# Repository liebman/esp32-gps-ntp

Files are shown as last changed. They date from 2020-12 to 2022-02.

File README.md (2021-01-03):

# This is an ESP32 NTP Server with DS3231 synched to GPS PPS signal

**NOTE: This is functional but *very much* a work in progress at the moment.**

This is an [esp-idf](https://docs.espressif.com/projects/esp-idf/en/latest/esp32/index.html) app using [platformio](https://platformio.org/).

## Some details

Synching the DS3231 to the GPS is done with a small high level (level 5) interrupt handler in assembly.  This generates a timestamp and offset in microseconds tracking the active edges of the GPS PPS and RTC SQW signals.  This data is then fed in to a PID algorithm that will generate an offset value used to speed up and slow down the DS3231 RTC.  This keeps the DS3231 synced with the GPS to within a couple of microseconds.  As a side benifit it also tunes the DS3231's ocilator to reduce drift when GPS is unavailable.

- [main](main) Contains the code
- [kicad/esp-gps-ntp](kicad/esp-gps-ntp) contains the schematic and board designs in KiCad.
- [kicad/display-adapter](kicad/display-adapter) contains the schematic and board design for a small adapter to config a single inline header connector to an IDC connector (for ribbon cable connection of display)

The display I'm using is [here](https://www.amazon.com/gp/product/B073R7BH1B)

## Schematic

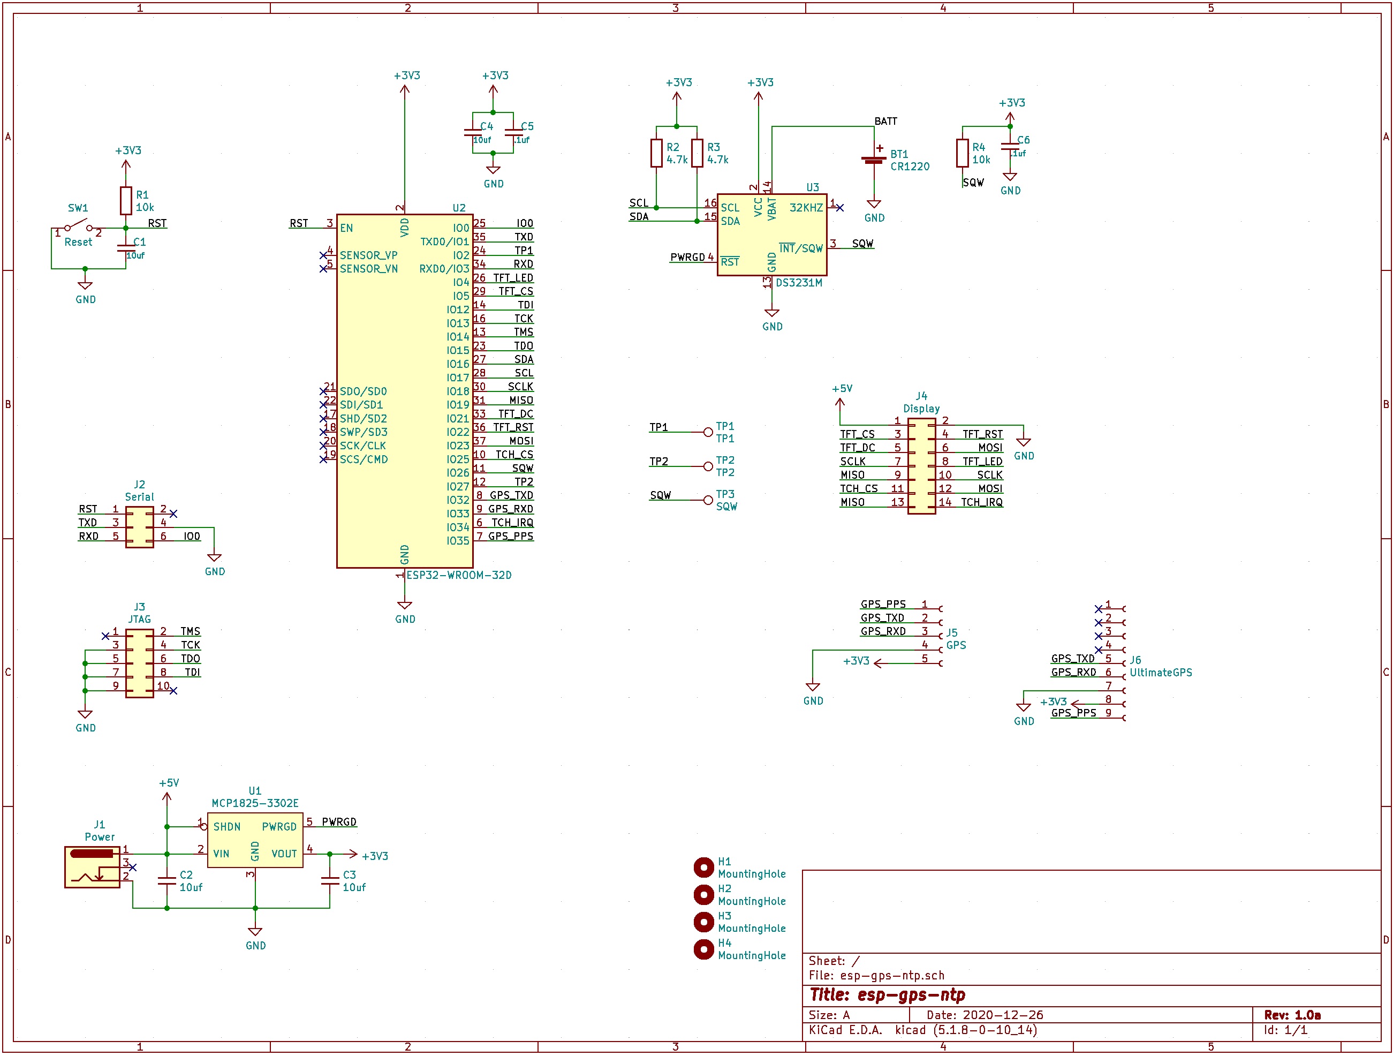
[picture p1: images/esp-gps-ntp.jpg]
Schematic


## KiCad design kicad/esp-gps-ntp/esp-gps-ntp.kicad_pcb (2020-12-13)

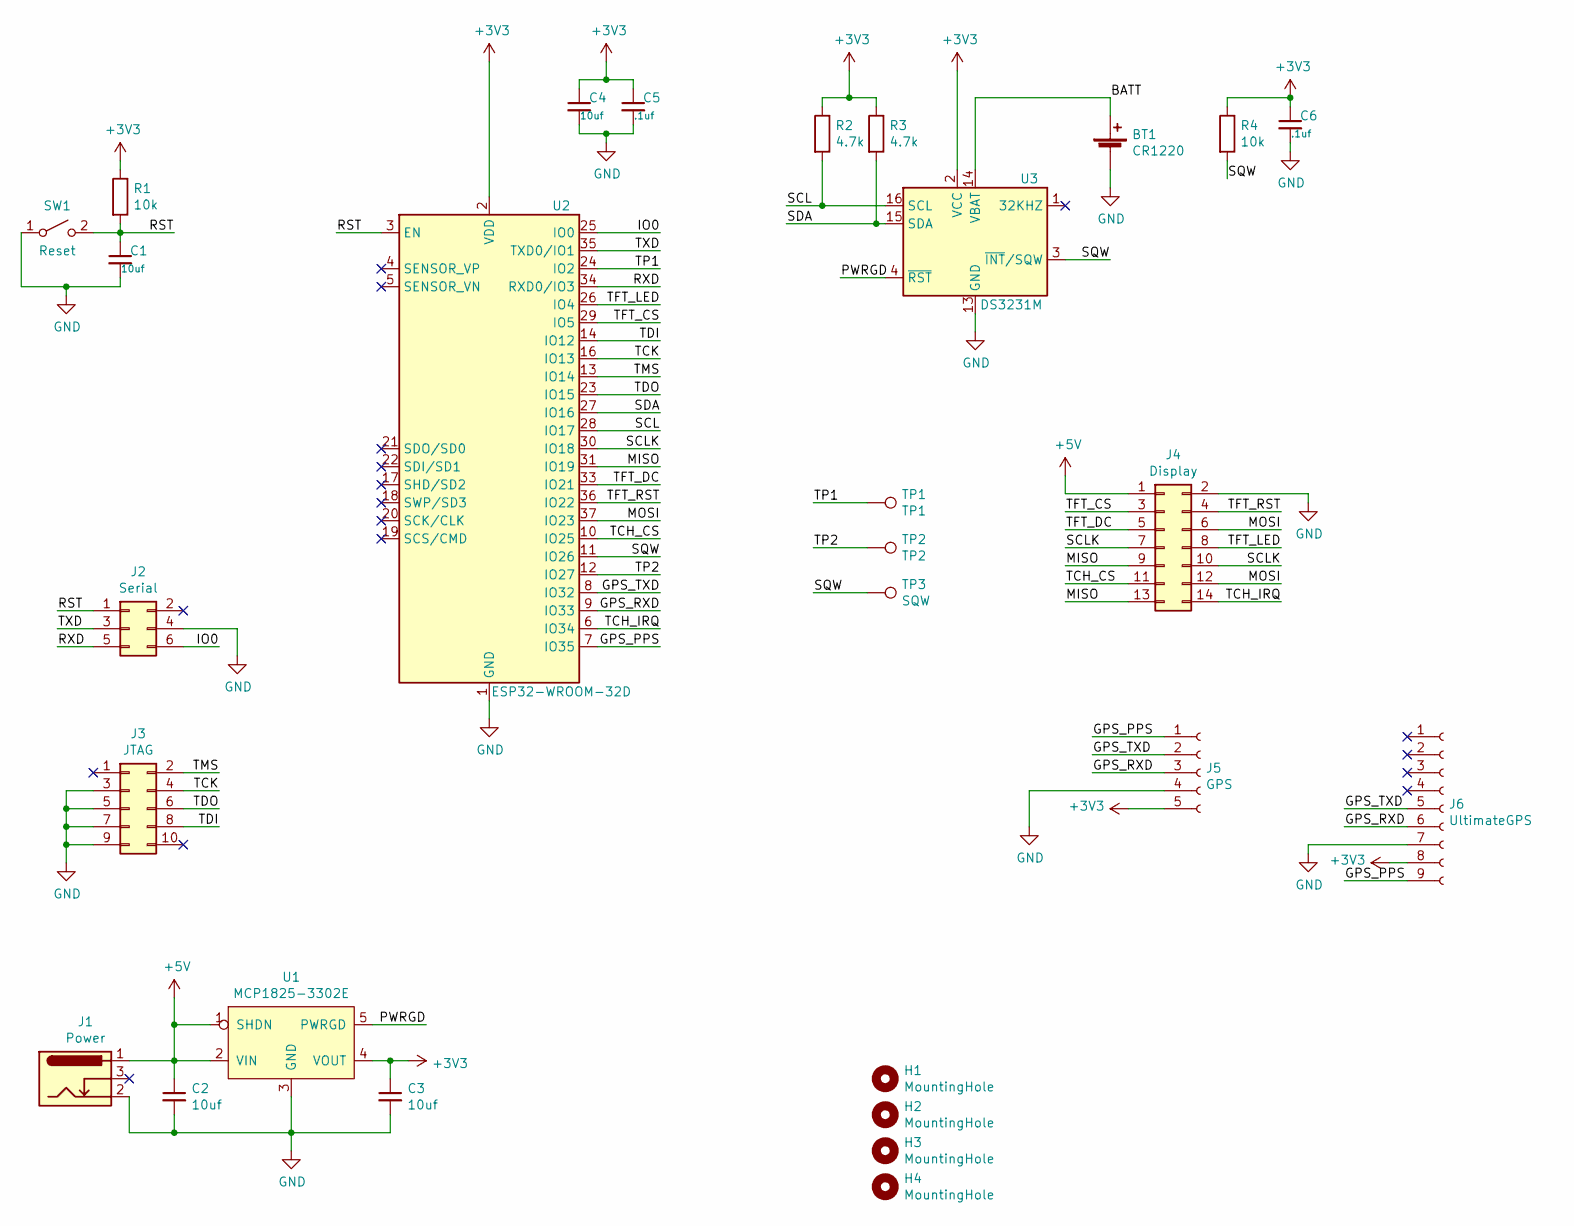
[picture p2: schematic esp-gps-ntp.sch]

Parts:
BT1: CR1220; HARWIN-CR1220
C1, C2, C3, C4: 10uf; C_Disc_D5.0mm_W2.5mm_P5.00mm
C5, C6: .1uf; C_Disc_D5.0mm_W2.5mm_P2.50mm
H1, H2, H3, H4: MountingHole; MountingHole_3.2mm_M3
J1: Power; BarrelJack_Horizontal
J2: Serial; IDC-Header_2x03_P2.54mm_Vertical
J3: JTAG; IDC-Header_2x05_P2.54mm_Vertical
J4: Display; IDC-Header_2x07_P2.54mm_Vertical
J5: GPS; PinSocket_1x05_P2.54mm_Vertical
J6: UltimateGPS; PinSocket_1x09_P2.54mm_Vertical
R1, R4: 10k; R_Axial_DIN0207_L6.3mm_D2.5mm_P7.62mm_Horizontal
R2, R3: 4.7k; R_Axial_DIN0207_L6.3mm_D2.5mm_P7.62mm_Horizontal
SW1: Reset; SW_PUSH_6mm
TP1: TP1; TestPoint_THTPad_2.5x2.5mm_Drill1.2mm
TP2: TP2; TestPoint_THTPad_2.5x2.5mm_Drill1.2mm
TP3: SQW; TestPoint_THTPad_2.5x2.5mm_Drill1.2mm
U1: MCP1825-3302E; SOT-223-6
U2: ESP32-WROOM-32D; ESP32-WROOM-32
U3: DS3231M; SOIC-16W_7.5x10.3mm_P1.27mm

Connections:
+3V3: C3.1, C4.1, C5.1, C6.1, J5.5, J6.8, R1.1, R2.1, R3.1, R4.1, U1.4 (VOUT), U2.2 (VDD), U3.2 (VCC)
+5V: C2.1, J1.1, J4.1, U1.1 (SHDN), U1.2 (VIN)
/BATT: BT1.1 (+), U3.14 (VBAT)
/GPS_PPS: J5.1, J6.9, U2.7 (IO35)
/GPS_RXD: J5.3, J6.6, U2.9 (IO33)
/GPS_TXD: J5.2, J6.5, U2.8 (IO32)
/IO0: J2.6, U2.25 (IO0)
/MISO: J4.9, J4.13, U2.31 (IO19)
/MOSI: J4.6, J4.12, U2.37 (IO23)
/PWRGD: U1.5 (PWRGD), U3.4 (~RST)
/RST: C1.1, J2.1, R1.2, SW1.2 (B), U2.3 (EN)
/RXD: J2.5, U2.34 (RXD0/IO3)
/SCL: R2.2, U2.28 (IO17), U3.16 (SCL)
/SCLK: J4.7, J4.10, U2.30 (IO18)
/SDA: R3.2, U2.27 (IO16), U3.15 (SDA)
/SQW: R4.2, TP3.1, U2.11 (IO26), U3.3 (~INT~/SQW)
/TCH_CS: J4.11, U2.10 (IO25)
/TCH_IRQ: J4.14, U2.6 (IO34)
/TCK: J3.4, U2.16 (IO13)
/TDI: J3.8, U2.14 (IO12)
/TDO: J3.6, U2.23 (IO15)
/TFT_CS: J4.3, U2.29 (IO5)
/TFT_DC: J4.5, U2.33 (IO21)
/TFT_LED: J4.8, U2.26 (IO4)
/TFT_RST: J4.4, U2.36 (IO22)
/TMS: J3.2, U2.13 (IO14)
/TP1: TP1.1, U2.24 (IO2)
/TP2: TP2.1, U2.12 (IO27)
/TXD: J2.3, U2.35 (TXD0/IO1)
GND: BT1.2 (-), C1.2, C2.2, C3.2, C4.2, C5.2, C6.2, J1.2, J2.4, J3.3, J3.5, J3.7, J3.9, J4.2, J5.4, J6.7, SW1.1 (A), U1.3 (GND), U1.6 (GND), U2.1 (GND), U2.15 (GND), U2.38 (GND), U2.39 (GND), U3.5 (GND), U3.6 (GND), U3.7 (GND), U3.8 (GND), U3.9 (GND), U3.10 (GND), U3.11 (GND), U3.12 (GND), U3.13 (GND)

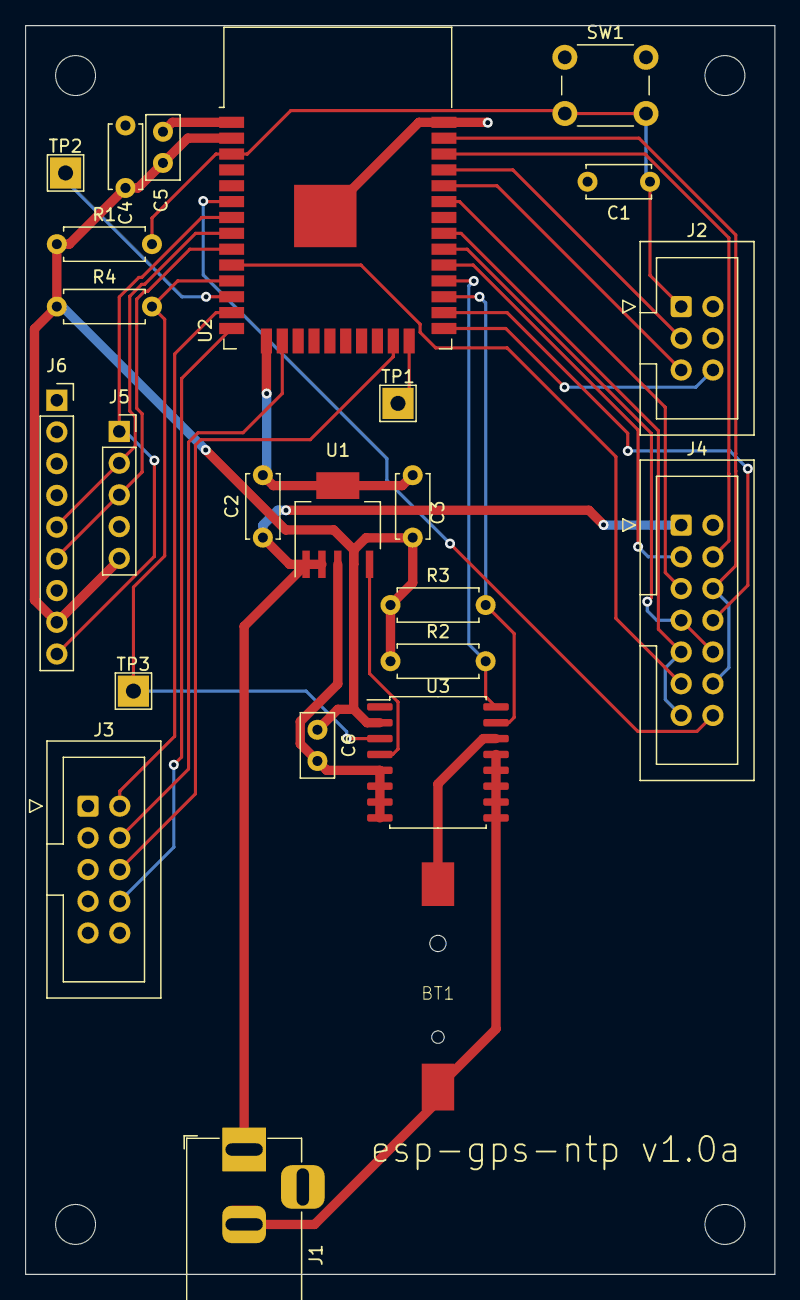
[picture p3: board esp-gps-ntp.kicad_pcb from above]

Board: 2 copper layers, 60.0 x 100.0 mm, 28 parts (0 on the bottom side), 30 nets.

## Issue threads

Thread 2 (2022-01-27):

Minimal example?

dizcza, 2022-01-27:
Hi, you've pointed out this repository in a discussion on the ESP32 forum.
Thanks for making the project available and open.
It does contain though things are not strictly related to DS3231+GPS synchronization. In particular, lots of code seem to be required just for a display to work. Could you please provide a minimal code that shows how to use an RTC with a GPS module?
You've described several things in the readme but I don't see the backbone - RTC+GPS sync. And there are several files in this repo, as I mentioned, some scripts are unrelated. I'm lost here.
It'd be helpful if you somehow point to and/or describe the synchronization part standalone.
Thank you.

liebman, 2022-01-27:
This is a bit rambling but maybe it will help:

The biggest trick was to use a high level interrupt (highint5.S) as that was the only way to service interrupts with consistently low latency.  This tracks time in microseconds for both GPS and PPS 1hz signals.

See `SyncManager.cpp`.  In particular `setTime()` sets the DS3231 time carefully to align as closely as possible with the DPS second change.  Also `recordOfset()`/`getOffset()` take the output from the `highint5` interrupt handler and generate an average delta that was measured between the two (GPS & DS3231) 1hz interrupt signals.  This average is used in a PID algorithm in `manageDrift()` to calculate a running correction and use it to adjust the AGE_OFFSET register to speed up or slow down the DS3231 to keep it in sync with GPS.  The `process()` function also handles when the DS3231 too far off to fix with AGE_OFFSET adjustments, and in that case it just sets the clock with `setTime()`.

dizcza, 2022-01-28:
Thanks, I'm currently inspecting the code. `highint5` routine is written in assembly, really love it (though I still don't understand assembly).
Two questions so far.
1. What's the GPS module you're using?
2. I'm running into an error while building the project:
```
../components/lvgl_esp32_drivers/lvgl_tft/ili9341.c: In function 'ili9341_init':
../components/lvgl_esp32_drivers/lvgl_tft/ili9341.c:94:9: error: implicit declaration of function 'gpio_pad_select_gpio'; did you mean 'esp_rom_gpio_pad_select_gpio'? [-Werror=implicit-function-declaration]
         gpio_pad_select_gpio(ILI9341_DC);
         ^~~~~~~~~~~~~~~~~~~~
         esp_rom_gpio_pad_select_gpio
```
I'm using the latest ESP-IDF master branch v5.0-dev-1373-g84d11d1c3e to build ESP32 projects. I could find neither declaration nor implementation of the `gpio_pad_select_gpio` function in the repo and its submodules.

dizcza, 2022-01-28:
All right, had to add
* `#include "rom/gpio.h"` in `ili9341.h` and
* `#include "soc/timer_group_struct.h"` in `MicroSecondTimer.h`
but now I get
```
In file included from ../main/MicroSecondTimer.h:30,
                 from ../main/PPS.h:33,
                 from ../main/NTP.h:27,
                 from ../main/NTP.cpp:25:
/media/dizcza/media/esp-idf/components/soc/esp32/include/soc/timer_group_struct.h:98:3: note: candidate: 'constexpr timg_txupdate_reg_t& timg_txupdate_reg_t::operator=(const timg_txupdate_reg_t&)'
 } timg_txupdate_reg_t;
   ^~~~~~~~~~~~~~~~~~~
/media/dizcza/media/esp-idf/components/soc/esp32/include/soc/timer_group_struct.h:98:3: note:   no known conversion for argument 1 from 'int' to 'const timg_txupdate_reg_t&'
/media/dizcza/media/esp-idf/components/soc/esp32/include/soc/timer_group_struct.h:98:3: note: candidate: 'constexpr timg_txupdate_reg_t& timg_txupdate_reg_t::operator=(timg_txupdate_reg_t&&)'
/media/dizcza/media/esp-idf/components/soc/esp32/include/soc/timer_group_struct.h:98:3: note:   no known conversion for argument 1 from 'int' to 'timg_txupdate_reg_t&&'
In file included from ../main/PPS.h:33,
                 from ../main/NTP.h:27,
                 from ../main/NTP.cpp:25:
../main/MicroSecondTimer.h:47:42: error: 'volatile struct timg_hwtimer_reg_t' has no member named 'cnt_low'
         return TIMERG0.hw_timer[TIMER_0].cnt_low;
                                          ^~~~~~~
../main/MicroSecondTimer.h: In member function 'uint32_t MicroSecondTimer::getValue()':
../main/MicroSecondTimer.h:56:44: error: no match for 'operator=' (operand types are 'volatile timg_txupdate_reg_t' and 'int')
         TIMERG0.hw_timer[TIMER_0].update = 1;
                                            ^
In file included from ../main/MicroSecondTimer.h:30,
                 from ../main/PPS.h:33,
                 from ../main/NTP.h:27,
                 from ../main/NTP.cpp:25:
/media/dizcza/media/esp-idf/components/soc/esp32/include/soc/timer_group_struct.h:98:3: note: candidate: 'constexpr timg_txupdate_reg_t& timg_txupdate_reg_t::operator=(const timg_txupdate_reg_t&)'
 } timg_txupdate_reg_t;
   ^~~~~~~~~~~~~~~~~~~
/media/dizcza/media/esp-idf/components/soc/esp32/include/soc/timer_group_struct.h:98:3: note:   no known conversion for argument 1 from 'int' to 'const timg_txupdate_reg_t&'
/media/dizcza/media/esp-idf/components/soc/esp32/include/soc/timer_group_struct.h:98:3: note: candidate: 'constexpr timg_txupdate_reg_t& timg_txupdate_reg_t::operator=(timg_txupdate_reg_t&&)'
/media/dizcza/media/esp-idf/components/soc/esp32/include/soc/timer_group_struct.h:98:3: note:   no known conversion for argument 1 from 'int' to 'timg_txupdate_reg_t&&'
In file included from ../main/PPS.h:33,
                 from ../main/NTP.h:27,
                 from ../main/NTP.cpp:25:
../main/MicroSecondTimer.h:57:42: error: 'volatile struct timg_hwtimer_reg_t' has no member named 'cnt_low'
         return TIMERG0.hw_timer[TIMER_0].cnt_low;
```
so I cannot build it with the newest ESP-IDF version. I need to know the ESP-IDF version this project was built with.

liebman, 2022-01-28:
IDF version 4.2
Note: I use `platformio` in most of my projects because it handles installing idf and tools (or development tools for many other platforms) without me having to manage it.

liebman, 2022-01-28:
For the GPS modules [this one](https://smile.amazon.com/gps/dp/B084MK8BS2) should work.  As well as [this one](https://smile.amazon.com/gp/product/B01H1R8BK0).

dizcza, 2022-01-28:
Thanks for the link, I've ordered three Neo-6M.

I've managed to build your project in the latest ESP-IDF version. Had to change several things, including a line here and there in the LVGL submodules. If you want, I could come up with a pull request with fixes once I understand the logic.
I see many debug lines like `#if 1... endif`, even in the `highint5` assembly file. Hope the way it's now is the working version and I don't need to comment/uncomment them out.

There are several options in the menuconfig, but I see the most important ones are in the `PPS.h`:

https://github.com/liebman/esp32-gps-ntp/blob/master/main/PPS.h#L35-L36

I have a feeling that I need to uncomment these both lines, right?

liebman, 2022-01-28:
No need to uncomment those - they were used when I was testing the `highint5` code and could be horribly broken.

A PR would be great, best if it can compile with both the old and new versions of IDF.

dizcza, 2022-01-28:
> No need to uncomment those - they were used when I was testing the highint5 code and could be horribly broken.
Ah, great, these defines cover quite a lot of code that I don't need to look into. And yes, uncommenting them breaks the build.

There are also `LATENCY_OUTPUT` and `SYNC_LATENCY_OUTPUT` that are never defined. I think I won't need them either.

> best if it can compile with both the old and new versions of IDF

then we need to get rid of hard-coded things

https://github.com/liebman/esp32-gps-ntp/blob/master/main/MicroSecondTimer.h#L46

and move to public API (uncomment the following lines in both timer functions). I don't know how much calling a function brings overhead, perhaps a dozen of nS which is tolerable for the precision of tens of uS.

liebman, 2022-01-28:
I used `LATENCY_OUTPUT` and `SYNC_LATENCY_OUTPUT` to toggle GPIOs to measure ISR latency.

You can use this to `#if` on the IDF version for specific features.  I want to keep the direct hardware access for the timer if possible.

```
#include "esp_idf_version.h"

#if ESP_IDF_VERSION >= ESP_IDF_VERSION_VAL(4, 0, 0)
    // enable functionality present in IDF v4.0
#endif
```

dizcza, 2022-02-04:
I got it working (without a display - I've detached the display part and print everything to console).
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
liebman, 2022-02-06:
What pull-up do you have on the RTC SQW signal?

dizcza, 2022-02-06:
No pull-up. As you do.

```
#define GPS_RX_PIN (GPIO_NUM_23)
#define GPS_TX_PIN (GPIO_NUM_19)
#define GPS_PPS_PIN ((gpio_num_t)GPIO_NUM_18)
#define RTC_PPS_PIN ((gpio_num_t)GPIO_NUM_33)
#define SDA_PIN (GPIO_NUM_4)
#define SCL_PIN (GPIO_NUM_22)

...

    // initialize I2C_NUM_0
    err = i2c_driver_install(I2C_NUM_0, I2C_MODE_MASTER, 0, 0, 0);
    if (err != ESP_OK)
    {
        ESP_LOGE(TAG, "i2c_driver_install: I2C_NUM_%d %d (%s)", I2C_NUM_0, err, esp_err_to_name(err));
    }
    i2c_config_t conf;
    conf.mode = I2C_MODE_MASTER;
    conf.sda_io_num = SDA_PIN;
    conf.scl_io_num = SCL_PIN;
    conf.sda_pullup_en = GPIO_PULLUP_DISABLE;
    conf.scl_pullup_en = GPIO_PULLUP_DISABLE;
    conf.master.clk_speed = 400000;
    err = i2c_param_config(I2C_NUM_0, &conf);
```

liebman, 2022-02-06:
It needs a pullup.  I have an external 10k on that signal.

dizcza, 2022-02-06:
Ah, I see. True, didn't think about that. All right, I'll add one and let you know.

liebman, 2022-02-06:
You should be able to use the internal pullup.

dizcza, 2022-02-06:
> You should be able to use the internal pullup.

yes, that's why I'll try first. Add internal pull-up for both SDA and SCL.

If not succeeded, I'll add an external one.

liebman, 2022-02-06:
I pushed the  timer updates, also added the same logic in `highint5.S`.  I did some tests adding to a counter in the wait loop.  I never saw it count so it must be a very rare occurrence.

dizcza, 2022-02-07:
Neither internal nor external (with internal turned off) pull-up resistors attached to RTC sda and scl pins helped.

I'm looking at the `PPS.begin()` function. Have you attached external pull-up/pull-down resistors here? I typically use an internal pull-up or pull-down resistor with GPIO interrupts. Found none in your code.

liebman, 2022-02-07:
External 10k (its in the schema R4 [here](https://github.com/liebman/esp32-gps-ntp/blob/master/images/esp-gps-ntp.jpg))

dizcza, 2022-02-08:
So I added an external 10k pull-up resistor for RTC SQW and a 10k pull-down resistor for GPS PPS (I think it's also needed though I didn't find one in your schematic), kept 10k external pull-ups for I2C and this didn't solve the issue. I got one such event in a night after I fixed the aging offset to the best value:

```
^[[0;33mW (01:26:14.120) SyncManager: ::recordOffset: RTC interval out of range: 500004^[[0m
^[[0;32mI (01:26:15.468) SyncManager: T 21.75, AGEOFFSET -17 (fixed), PPM 0.0010 (-10.1 us / 10294 s)^[[0m
^[[0;32mI (01:26:20.115) SyncManager: setTime succeeded; GPS microseconds=999800, loops=336818^[[0m
^[[0;33mW (01:26:20.126) SyncManager: time correction happened!  PPS offset=-10.000 us gps_time=1644283579 rtc_time=1644283580^[[0m
^[[0;32mI (01:26:20.134) SyncManager: GPS Interval: 1000009^[[0m
^[[0;32mI (01:26:20.142) SyncManager: GPS Min/Max: 1000008 / 1000010^[[0m
^[[0;32mI (01:26:20.150) SyncManager: GPS Short/Long: 0 / 2^[[0m
^[[0;32mI (01:26:20.158) SyncManager: RTC Interval: 1000009^[[0m
^[[0;32mI (01:26:20.165) SyncManager: RTC Min/Max: 1000009 / 1000014^[[0m
^[[0;32mI (01:26:20.173) SyncManager: RTC Short/Long: 2 / 2^[[0m
^[[0;33mW (01:26:21.931) SyncManager: ::recordOffset: RTC interval out of range: 2000019^[[0m
```

I'll try running the app without fixing the aging offset but I don't think it'll help. Even if it helps, the problem won't be solved.

I need to perform more long-running tests without resetting the clocks on these events and see what offsets in both seconds and microseconds
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

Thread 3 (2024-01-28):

LVTabView.h

mohog, 2024-01-28:
Can you point me to where to find this item?

In file included from /esp32-gps-ntp-master/main/main.ino:32:
/esp32-gps-ntp-master/main/Display.h:30:10: fatal error: LVTabView.h: No such file or directory
   30 | #include "LVTabView.h"
      |          ^~~~~~~~~~~~~
compilation terminated.
exit status 1

Compilation error: LVTabView.h: No such file or directory

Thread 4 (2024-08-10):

Stack sizes and platform version issues/questions

ntmmfts, 2024-08-10:
Hi, thanks for this project, haven't seen any others like it - especially with a PID written in assembly...

Having issues getting past canary watchpoint errors despite efforts adjusting stack sizes, and also issues with the platform version set in the repo.  Got past working sizes for Tmr and IDLE, but get cpu 0 scheduler aborts with any other stack adjustments and no indication which stack causes it.  When I get to this point, the backtrace decoder indicates it could be ESP_EARLY_LOGI(TAG, "Pro cpu start user code"); - and googling says that could be early debug logging before cpu is started - maybe for the stack size problems.

I saw your discussion with @dizcza and your mention of using version 4.2, but the platformio.ini in the repo still specifies 3.0.0.  I can't get it to build when setting it to 4.0.0 due to endless mirror searches for matching tools, and also issues building with current 5.x with various deprecation and syntax issues.

Asking if you can update the sdkconfig with stack sizes that work with 3.0.0 or update everything to version 4 or 5 if you have either of those working.

Thanks again for this amazing work - I intend to leverage it in my (unpublished) WWVB emulator project for transmitting timecode as close to UTC as possible - currently getting sub 50ms precision without a PID.  No time signal in Hawaii so I have to do it myself :-).

liebman, 2024-08-11:
I'm not goingto get to that anytime soon :-(.  But at some point I'll probably re-implement this using [rust](https://github.com/esp-rs/esp-hal/tree/main) and using the MCPWM peripherals capture feature. I would accept PRs if you manage to upgrade it.

ntmmfts, 2024-08-15:
Ended up disabling brownout detection and disabling CONFIG_ESP_PHY_INIT_DATA_IN_PARTITION while the project is running off of USB power on a breadboard.  Now encountering what looks like I2C and SPI conflicting which is making RTC reads irratic and freezing the display.  This may be a documented problem from earlier esp-idf versions but didn't find anything specific for 3.0.0 and its updates.  All of this may just be power related, but at least I'm past bootup - gonna power the components separately and see what happens.

ntmmfts, 2024-08-16:
Got it working, it was a breadboard wiring issue.  Going to review your conversation with @dizcza and experiment with those tweaks.

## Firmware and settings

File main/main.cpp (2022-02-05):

/*
 * MIT License
 *
 * Copyright (c) 2020 Christopher B. Liebman
 *
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
 * THE SOFTWARE IS PROVIDED "AS IS", WITHOUT WARRANTY OF ANY KIND, EXPRESS OR
 * IMPLIED, INCLUDING BUT NOT LIMITED TO THE WARRANTIES OF MERCHANTABILITY,
 * FITNESS FOR A PARTICULAR PURPOSE AND NONINFRINGEMENT. IN NO EVENT SHALL THE
 * AUTHORS OR COPYRIGHT HOLDERS BE LIABLE FOR ANY CLAIM, DAMAGES OR OTHER
 * LIABILITY, WHETHER IN AN ACTION OF CONTRACT, TORT OR OTHERWISE, ARISING FROM,
 * OUT OF OR IN CONNECTION WITH THE SOFTWARE OR THE USE OR OTHER DEALINGS IN THE
 * SOFTWARE.
*/

#include "freertos/FreeRTOS.h"
#include "freertos/task.h"
#include "driver/gpio.h"
#include "nvs_flash.h"
#include "esp_log.h"

#include "Config.h"
#include "Display.h"
#include "Network.h"
#include "DS3231.h"
#include "MicroSecondTimer.h"
#include "PPS.h"
#include "GPS.h"
#include "NTP.h"
#include "SyncManager.h"

#include "PageAbout.h"
#include "PageConfig.h"
#include "PagePPS.h"
#include "PageDelta.h"
#include "PageSync.h"
#include "PageGPS.h"
#include "PageSats.h"
#include "PageNTP.h"

#define LATENCY_PIN 2
#define LATENCY_SEL (1<<LATENCY_PIN)

#ifdef __cplusplus
//
// app_main() is called from C
//
extern "C" {
    void app_main(void);
}
#endif

#if defined(CONFIG_GPSNTP_RTC_DRIFT_MAX)
#define RTC_DRIFT_MAX CONFIG_GPSNTP_RTC_DRIFT_MAX
#else
#define RTC_DRIFT_MAX 500
#endif

#define GPS_RX_PIN (GPIO_NUM_33)
#define GPS_TX_PIN (GPIO_NUM_32)
#define GPS_PPS_PIN ((gpio_num_t)CONFIG_GPSNTP_PPS_PIN)
#define RTC_PPS_PIN ((gpio_num_t)CONFIG_GPSNTP_SQW_PIN)
#define SDA_PIN (GPIO_NUM_16)
#define SCL_PIN (GPIO_NUM_17)
#define TFT_LED_PIN (GPIO_NUM_4)
#define TFT_LED_SEL (GPIO_SEL_4)
#define TCH_IRQ_PIN ((gpio_num_t)CONFIG_LV_TOUCH_PIN_IRQ)
#if CONFIG_LV_TOUCH_PIN_IRQ < 32
#define TCH_IRQ_SEL (1<<CONFIG_LV_TOUCH_PIN_IRQ)
#else
#define TCH_IRQ_SEL ((uint64_t)(((uint64_t)1)<<CONFIG_LV_TOUCH_PIN_IRQ))
#endif

static const char* TAG = "main";


extern pps_data_t rtc_pps_data; // in highint5.S
extern pps_data_t gps_pps_data; // in highint5.S

static Config config;
static MicroSecondTimer usec_timer;
static PPS gps_pps(usec_timer, &gps_pps_data);
static PPS rtc_pps(usec_timer, &rtc_pps_data, &gps_pps); // use gps_pps as ref.
static GPS gps(usec_timer);
static DS3231 rtc;
static NTP ntp(rtc_pps);
static SyncManager syncman(gps, rtc, gps_pps, rtc_pps);

static void apply_config()
{
    ESP_LOGI(TAG, "apply_config()");
    syncman.setBias(config.getBias());
    syncman.setTarget(config.getTarget());
}

static void init(void* data)
{
    (void)data;
    ESP_LOGI(TAG, "init: with priority %d core %d", uxTaskPriorityGet(nullptr), xPortGetCoreID());

    esp_err_t err;
    gpio_config_t io_conf;

#ifdef LATENCY_OUTPUT
    ESP_LOGI(TAG, "configuring LATENCY_PIN pin %d", LATENCY_PIN);
    io_conf.pin_bit_mask = LATENCY_SEL;
    io_conf.mode = GPIO_MODE_OUTPUT;
    io_conf.intr_type = GPIO_INTR_DISABLE;
    io_conf.pull_down_en = GPIO_PULLDOWN_DISABLE;
    io_conf.pull_up_en = GPIO_PULLUP_DISABLE;
    err = gpio_config(&io_conf);
    if (err != ESP_OK)
    {
        ESP_LOGE(TAG, "failed to init LATENCY_PIN pin as output: %d '%s'", err, esp_err_to_name(err));
    }
#endif

    ESP_LOGI(TAG, "init: starting display");
    if (!Display::getDisplay().begin())
    {
        ESP_LOGE(TAG, "init: failed to initialize display!");
    }

    // turn the backlight on.
    ESP_LOGI(TAG,  "turning backlight on");
    io_conf.pin_bit_mask = TFT_LED_SEL;
    io_conf.mode = GPIO_MODE_OUTPUT;
    io_conf.intr_type = GPIO_INTR_DISABLE;
    io_conf.pull_down_en = GPIO_PULLDOWN_DISABLE;
    io_conf.pull_up_en = GPIO_PULLUP_DISABLE;
    err = gpio_config(&io_conf);
    if (err != ESP_OK)
    {
        ESP_LOGE(TAG, "failed to init backlight pin as output: %d '%s'", err, esp_err_to_name(err));
    }
    // turn the backlight on.
    gpio_set_level(TFT_LED_PIN, 1);

    // initialize I2C_NUM_0
    err = i2c_driver_install(I2C_NUM_0, I2C_MODE_MASTER, 0, 0, 0);
    if (err != ESP_OK)
    {
        ESP_LOGE(TAG, "i2c_driver_install: I2C_NUM_%d %d (%s)", I2C_NUM_0, err, esp_err_to_name(err));
    }
    i2c_config_t conf;
    conf.mode = I2C_MODE_MASTER;
    conf.sda_io_num = SDA_PIN;
    conf.scl_io_num = SCL_PIN;
    conf.sda_pullup_en = GPIO_PULLUP_DISABLE;
    conf.scl_pullup_en = GPIO_PULLUP_DISABLE;
    conf.master.clk_speed = 400000;
    err = i2c_param_config(I2C_NUM_0, &conf);
    if (err != ESP_OK)
    {
        ESP_LOGE(TAG, "i2c_param_config: I2C_NUM_%d %d (%s)", I2C_NUM_0, err, esp_err_to_name(err));
    }

    while (!rtc.begin())
    {
        ESP_LOGE(TAG, "failed to start rtc!");
        vTaskDelay(pdMS_TO_TICKS(100));
    }

    // start gps watching NMEA messages
    // swap rx/tx as GPS_RX is our TX!
    if (!gps.begin(GPS_RX_PIN, GPS_TX_PIN))
    {
        ESP_LOGE(TAG, "failed to start gps!");
    }

    // start pps watching gps
    if (!gps_pps.begin(GPS_PPS_PIN))
    {
        ESP_LOGE(TAG, "failed to start GPS pps!");
    }

    // start pps watching rtc
    if (!rtc_pps.begin(RTC_PPS_PIN, true))
    {
        ESP_LOGE(TAG, "failed to start RTC pps!");
    }

    // wait for the RTC PPS signal to be low, the first half of a secondm, so we
    // don't do this on a second boundry as the RTC PPS could get or miss an increment.
    ESP_LOGI(TAG, " waiting a change in seconds");
    time_t now = rtc_pps.getTime(nullptr);
    while(rtc_pps.getTime(nullptr) == now)
    {
        vTaskDelay(pdMS_TO_TICKS(50));
    }
    ESP_LOGI(TAG, "setting time on RTC pps");
    struct tm tm;
    rtc.getTime(&tm);
    rtc_pps.setTime(mktime(&tm));

    // start NTP services
    ntp.begin();

    // start the sync manager
    syncman.begin();

    new PageNTP(ntp, syncman);
    new PagePPS(gps_pps, rtc_pps);
    new PageSync(syncman);
    new PageDelta(syncman);
    new PageGPS(gps);
    new PageSats(gps);
    new PageConfig(config, apply_config);
    new PageAbout();

    vTaskDelete(NULL);
}

void app_main()
{
    ESP_LOGI(TAG, "Starting with priority %d core %d", uxTaskPriorityGet(nullptr), xPortGetCoreID());
    //Initialize NVS
    ESP_LOGI(TAG, "initializing NVS");
    esp_err_t ret = nvs_flash_init();
    if (ret == ESP_ERR_NVS_NO_FREE_PAGES || ret == ESP_ERR_NVS_NEW_VERSION_FOUND) {
      ESP_ERROR_CHECK(nvs_flash_erase());
      ret = nvs_flash_init();
    }
    ESP_ERROR_CHECK(ret);

    config.begin();
    config.load();
    apply_config();

    xTaskCreatePinnedToCore(&init, "init", 4096, nullptr, 1, nullptr, 1);

    ESP_LOGI(TAG, "initializing Network");
    Network::getNetwork().begin(config.getWiFiSSID(), config.getWiFiPassword());

    bool was_valid = false;
    bool is_on = true;

    while(true)
    {
        struct timeval gps_tv;
        gps_pps.getTime(&gps_tv);
        bool now_valid = gps.getValid();
        if (was_valid != now_valid)
        {
            ESP_LOGW(TAG, "gps %s validity!", now_valid ? "gained" : "lost");
            was_valid = now_valid;
        }

        if (Display::getDisplay().getIdleTime() > 3600) // 1 hr
        {
            if (is_on)
            {
                ESP_LOGI(TAG, "turning OFF backlight");
                gpio_set_level(TFT_LED_PIN, 0);
                is_on = false;
            }
        }
        else if (!is_on)
        {
            ESP_LOGI(TAG, "turning ON backlight");
            gpio_set_level(TFT_LED_PIN, 1);
            is_on = true;
        }

        vTaskDelay(pdMS_TO_TICKS(100));
    }
}

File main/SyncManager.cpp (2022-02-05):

/*
 * MIT License
 *
 * Copyright (c) 2020 Christopher B. Liebman
 *
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
 * THE SOFTWARE IS PROVIDED "AS IS", WITHOUT WARRANTY OF ANY KIND, EXPRESS OR
 * IMPLIED, INCLUDING BUT NOT LIMITED TO THE WARRANTIES OF MERCHANTABILITY,
 * FITNESS FOR A PARTICULAR PURPOSE AND NONINFRINGEMENT. IN NO EVENT SHALL THE
 * AUTHORS OR COPYRIGHT HOLDERS BE LIABLE FOR ANY CLAIM, DAMAGES OR OTHER
 * LIABILITY, WHETHER IN AN ACTION OF CONTRACT, TORT OR OTHERWISE, ARISING FROM,
 * OUT OF OR IN CONNECTION WITH THE SOFTWARE OR THE USE OR OTHER DEALINGS IN THE
 * SOFTWARE.
*/

#include "SyncManager.h"
//#define LOG_LOCAL_LEVEL ESP_LOG_DEBUG
#include "esp_log.h"

#if defined(CONFIG_GPSNTP_RTC_DRIFT_MAX)
#define RTC_DRIFT_MAX CONFIG_GPSNTP_RTC_DRIFT_MAX
#else
#define RTC_DRIFT_MAX 500
#endif

#ifndef SYNC_TASK_PRI
#define SYNC_TASK_PRI configMAX_PRIORITIES
#endif

#ifndef SYNC_TASK_CORE
#define SYNC_TASK_CORE 1
#endif

#define LATENCY_PIN 2

static const char* TAG = "SyncManager";

SyncManager::SyncManager(GPS& gps, DS3231& rtc, PPS& gpspps, PPS& rtcpps)
: _gps(gps),
  _rtc(rtc),
  _gpspps(gpspps),
  _rtcpps(rtcpps)
{
}

bool SyncManager::begin()
{
    ESP_LOGI(TAG, "::begin create Sync task at priority %d core %d", SYNC_TASK_PRI, SYNC_TASK_CORE);
    xTaskCreatePinnedToCore(task, "Sync", 4096, this, SYNC_TASK_PRI, &_task, SYNC_TASK_CORE);
    return true;
}

time_t SyncManager::getGPSTime()
{
    return _gps.getRMCTime();
}

time_t SyncManager::getRTCTime()
{
    return _rtc_time;
}

void SyncManager::getRTCPPSTime(struct timeval* tv)
{
    _rtcpps.getTime(tv);
}

void SyncManager::getGPSPPSTime(struct timeval* tv)
{
    _gpspps.getTime(tv);
}

float SyncManager::getError()
{
    return _target - (float)getOffset();
}

float SyncManager::getPreviousError()
{
    return _previous_error;
}

float SyncManager::getIntegral()
{
    return _integral;
}

uint32_t SyncManager::getUptime()
{
    return (esp_timer_get_time() / 1000000);
}

void SyncManager::recordOffset()
{
    static time_t last_rtc = 0;
    static time_t last_gps = 0;
    time_t rtc_time = _rtcpps.getTime(nullptr);
    time_t gps_time = _gpspps.getTime(nullptr);

    // we want a change in both second counters before we take a new sample
    if (gps_time == last_gps || rtc_time == last_rtc)
    {
        return;
    }

    last_rtc = rtc_time;
    last_gps = gps_time;

    _offset_data[_offset_index++] = _rtcpps.getOffset();

    if (_offset_index >= OFFSET_DATA_SIZE)
    {
        _offset_index = 0;
    }

    if (_offset_count < OFFSET_DATA_SIZE)
    {
        _offset_count += 1;
    }

    uint32_t gps_interval = _gpspps.getTimerInterval();
    uint32_t rtc_interval = _rtcpps.getTimerInterval();
    if (rtc_interval < 999950 || rtc_interval > 1000050)
    {
        ESP_LOGW(TAG, "::recordOffset: RTC interval out of range: %u", rtc_interval);
    }
    if (gps_interval < 999950 || gps_interval > 1000050)
    {
        ESP_LOGW(TAG, "::recordOffset: GPS interval out of range: %u", gps_interval);
    }
}

bool SyncManager::isOffsetValid()
{
    return _offset_count == OFFSET_DATA_SIZE;
}

float SyncManager::getBias()
{
    return _bias;
}

void SyncManager::setBias(float bias)
{
    ESP_LOGI(TAG, "setBias: %0f", bias);
    _bias = bias;
    resetOffset();
}

float SyncManager::getTarget()
{
    return _target;
}

void SyncManager::setTarget(float target)
{
    ESP_LOGI(TAG, "setTarget: %0f", target);
    _target = target;
    resetOffset();
}

bool SyncManager::isValid()
{
    return _gps.getValid();
}

uint32_t SyncManager::getValidDuration()
{
    return _gps.getValidDuration();
}

uint32_t SyncManager::getValidCount()
{
    return _gps.getValidCount();
}

int8_t SyncManager::getOutput()
{
    return _output;
}

/**
 * return the average offset.  0 is returnerd if the offset data is not full.
*/
float SyncManager::getOffset(int32_t* minp, int32_t* maxp)
{
    if (_offset_count < OFFSET_DATA_SIZE)
    {
        return 0;
    }

    float total        = _offset_data[0];
    int32_t min_offset = _offset_data[0];
    int32_t max_offset = _offset_data[0];

    for(uint32_t i = 1; i < _offset_count; ++i)
    {
        total += _offset_data[i];
        if (_offset_data[i] < min_offset)
        {
            min_offset = _offset_data[i];
        }
        if (_offset_data[i] > max_offset)
        {
            max_offset = _offset_data[i];
        }
    }
    // throw out the min and max values
    total -= min_offset;
    total -= max_offset;
    float offset = total / ((float)OFFSET_DATA_SIZE-2);
    if (minp != nullptr)
    {
        *minp = min_offset;
    }
    if (maxp != nullptr)
    {
        *maxp = max_offset;
    }
    return offset;
}

void SyncManager::resetOffset()
{
    _offset_index = 0;
    _offset_count = 0;
    // reset PID controler as its invalid when we set the or finish adjusting
    _drift_start_time = 0;
    _integral = 0;
    _previous_error = 0;
}
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

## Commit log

2020-09-13 basic uart reading/logging
2020-09-14 switching to lvgl master
2020-09-15 added timer, just counting now, no resets.
    [GPS.cpp, main.cpp]
2020-09-15 fix baud rate for adafruit gps
    [GPS.cpp]
2020-09-16 use timer to detect missing PPS signals
    [GPS.cpp]
2020-09-22 increase uart buffer, backlight off timer
2020-09-23 update lvgl to current master v7.6.0+
2020-09-25 include config for GPS type & set baud rate set system time and track current time in seconds
2020-09-26 configure gps type increment time only not short
    [GPS.cpp]
2020-09-26 track unix time in seconds from pps
2020-10-03 configure fort esp32ntp-v0.1 board!
2020-10-03 fix timer interrupt
2020-10-11 make the timer choice configurable in menuconfig
2020-10-11 move microsecond timer out of GPS
2020-10-11 make timer values configurable
2020-10-14 display last short valuye
    [GPS.cpp]
2020-10-19 change timer to increase only, no interrupts
2020-11-04 for now use ULP for latency pin
2020-11-07 added simple drift compensation (WIP)
    [DS3231.cpp, PPS.cpp, SyncManager.cpp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]
2020-11-08 fix drift adjustment calculation in DS3231
    [DS3231.cpp]
2020-11-08 cleanup drift/adjustment a bit
    [DS3231.cpp, SyncManager.cpp, SyncManager.h]
2020-11-08 switch to drift_adjust
2020-11-08 Fix logic issue with start/end adjustments
    [SyncManager.cpp]
2020-11-13 use a PID controler to adjust rtc timeing (roughly tuned)
2020-11-14 show a second graph with error by second
    [SyncManager.cpp, SyncManager.h]
2020-11-15 added config with bias setting
    [partitions.csv]
2020-11-16 Use direct register access in ISR for GPIO. Use ionly 32 bits from us timer
2020-11-27 updated esp32 drivers
    [partitions.csv]
2020-11-27 updated drivers
2020-12-03 Board 1.0
    [esp-gps-ntp.kicad_pcb, esp-gps-ntp.sch]
2020-12-08 use pin number to check interrupt
2020-12-10 fixes for highint + using new board
    [PPS.cpp, SyncManager.cpp, main.cpp]
2020-12-11 implement min/max counting in asm isr (min is broken I think)
    [PPS.cpp]
2020-12-13 new board version fix idle time hack
    [esp-gps-ntp.kicad_pcb, esp-gps-ntp.sch]
2020-12-14 checkin display adapter
    [display-adapter.kicad_pcb, display-adapter.sch]
2020-12-19 upgrade platform to pickup newer openocd for esp32 v3
2020-12-19 use microsecond timer for gps rmc message timestamps
2020-12-23 attempt submodule for drivers
2020-12-24 used fixed touch idle time for backlight on/off
    [main.cpp]
2020-12-26 create initial readme
    [esp-gps-ntp.sch]
2020-12-26 fix README schematic link
2020-12-29 update esp32_drivers
2020-12-30 update lvgl to current master
2021-01-03 revert Kp value, still could use a better tuning
    [SyncManager.cpp, SyncManager.h]
2021-01-30 fix compile with interrupt_service (only used for some testing)
    [PPS.cpp]
2022-02-05 remove code no longer needed
    [PPS.cpp]
2022-02-06 added wait's when reading the hardware timer registers
